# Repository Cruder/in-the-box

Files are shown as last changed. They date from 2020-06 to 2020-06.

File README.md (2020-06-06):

## InTheBox

Connect your mailbox to be notified as soon as you receive mail.
InTheBox is also able to detect and warn you of suspicious behaviors around your mailbox.

demo

### Supplies
#### Circuit
- [Tags 13.56MHz](https://fr.aliexpress.com/item/33026471651.html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,searchweb201602_,searchweb201603_) 
- [RFID module 13.56MHz](https://fr.aliexpress.com/item/32803014822.html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)
- [Arduino Yun](https://store.arduino.cc/arduino-yun)
- [FSR 406](https://fr.aliexpress.com/item/32652992847.html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,searchweb201602_,searchweb201603_)
- [HC-SR04](https://fr.aliexpress.com/item/32973373842.html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,searchweb201602_,searchweb201603_)
- [Buzzer](https://fr.aliexpress.com/item/4000012077642.html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)
- [Pile 6V](https://fr.aliexpress.com/item/32971590400.html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,searchweb201602_,searchweb201603_)
- [RGB LED](https://www.amazon.fr/SODIAL-diode-electroluminescente-tete-ronde/dp/B00F4MGA0I?ref_=fsclp_pl_dp_2)

#### Scale
- 1 board 30 x 41 x 0.5 cm
- [Pressure Sensor Pad GreenS40](https://fr.aliexpress.com/item/4000416208703.html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,searchweb201602_,searchweb201603_)

#### Dummy soil
- 1 board 30 x 41 x 1 cm
- 2 boards 35 x 41 x 1 cm
- 1 board 35 x 28 x 1 cm
- 1 cylinder 35 cm x 1 cm radius
- screws / glue
- Something to cut out of the board 

### Step 1 - Tags initialization
The device uses key badges and an RFID reader to identify the person who opens the mailbox. This allows, among other things, to: 
- Not notify if the mailbox is opened with the badge nearby.
- Notify if mail is added to or removed from the mailbox without a badge nearby.
The drive range is 10 cm.

The first step is to register the badges used using the RFID module.
Copy [the code in the RFID/identify.ino](https://github.com/Cruder/in-the-box/blob/master/RFID/identify.ino) to identify the tags UID, following this fritzing schema:




(Credit code to https://www.electronique-mixte.fr/microcontrolleurs/rfid-controle-dacces-par-badge-avec-arduino/) 

### Step 2 - Assembly of the components
Fritzing schemas:
Fritzing
Fritzing2

### Step 3 - Mailbox measurement
We need to know the dimensions of the mailbox in order to build the layout and configure the distance sensor.
Measures the inner width and depth.

### Step 4 - Web server
#### Requirements
- You must install [Mint Lang](https://www.mint-lang.com).
- If you are using Windows, you will need to install Docker [Docker](https://www.docker.com/get-started).

#### Installation
- Go to the `notifier` folder
- Run `mint install`

#### Run
To start the server, run `mint start`



### Step 5 - Arduino code and component testing
The code is available on this TinkerCAD simulation: https://www.tinkercad.com/things/1rgmoFdLwcb
Copy it to your arduino, then modify this line to indicate the depth of your mailbox in millimetres:
```
#define MAIL_BOX_DEPTH 500
```
Then add the tags UID to the configuration.

Now you'd like to test your component assembly and configuration before moving them into the mailbox.

### Step 6 - Fabrication of dummy soil
The plan has been calculated for a letterbox with the dimensions 30 x 41 x 30 cm (L x W x H).
To readjust the plan to the dimensions of your letterbox, make sure that the false floor board (initially 30 x 41 x 1 cm) passes through the door horizontally before assembling.
supplies
plan cache

If you have a 3D printer, you can find [here](https://github.com/Cruder/in-the-box/tree/master/dummy_soil) a model to print yourself.

Follow these these assembly instructions:
1. Perce a slot in the back centre of the board measuring 30 x 41 x 1 cm, 2 cm wide and 15 cm long. This will allow the FSR sensor wires to disappear under the cover.

Capture d’écran du 2020-06-05 17-51-12

2. Turn the board so that you have the slot in front of you. Attach the 2 boards 35 x 41 x 1 cm on each side vertically to the board. 

Capture d’écran du 2020-06-05 17-54-19

3. On the other side, attach the 35 x 28 x 1 cm board vertically to the main board.

Capture d’écran du 2020-06-05 17-57-36

4. In the centre of the main board, 4 cm from the slot, attach the cylinder. Be careful not to let the screw protrude from the other side of the board, we will install the FSR sensor there.

Capture d’écran du 2020-06-05 17-58-23

### Step 7 - Arrangement of the letter box 
1. Place the arduino and its components at the bottom of the mailbox. The RFID sensor must be placed on the front or rear lock side. Its location will have an impact on the quality of authentication, and you will need to retrieve mail from this side only. 
2. Place the dummy soil in the mailbox, slot towards the back door. Be careful not to crush any components with the support foot of the dummy soil.
3. Fix the FSR sensor in the center of the dummy soil, tab towards the slot so the wires slide beneath. Pass the HC-SR04 sensor through the slot, we will fix it later at the back of the mailbox.
Capture d’écran du 2020-06-05 13-12-44
4. Fix the pressure pad on the FSR sensor.
Capture d’écran du 2020-06-05 13-13-01
5. Place the 30 x 41 x 0.5 cm board on top to make the scale.
Capture d’écran du 2020-06-05 13-26-51
6. Place the HC-SR04 sensor at the back of the mailbox on the side where the lock of the front door is located, and do some tests!
7. Then you can fix the HC-SR04 sensor

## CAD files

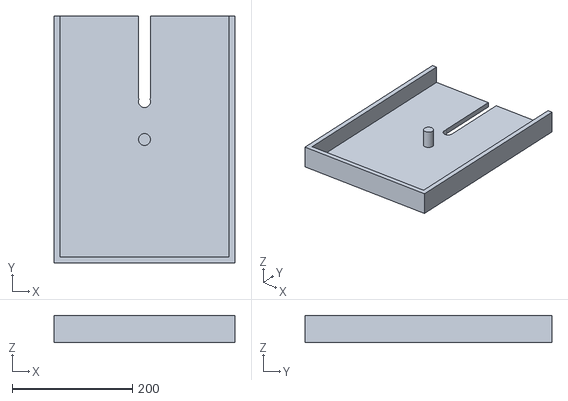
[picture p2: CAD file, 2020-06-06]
dummy_soil/tinker.obj
300.0 x 410.0 x 45.0

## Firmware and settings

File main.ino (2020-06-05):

#include <Keypad.h>

#define PIN_POTEN A0

#define PIN_HC_TRIG 3
#define PIN_HC_ECHO 2

#define RESET_PIN 13

#define PIN_BUZZER 12

// 1 minute, 60 000ms
#define FORCE_TIME_THRESSHOLD 60000UL
// Detect 1% force changes
// this avoid falsey positives
#define FORCE_THRESSHOLD 1

// Echo timeout from the HC module
#define MEASURE_TIMEOUT 25000UL

// Send notif if open 5s
#define DEPTH_MESURE_THRESSHOLD 5000

// Mailbox distance = 500mm
#define MAIL_BOX_DEPTH 500

/* Vitesse du son dans l'air en mm/us */
const float SOUND_SPEED = 340.0 / 1000;

unsigned long previous_force_time;
int previous_force;

// 0 = close
// 1 = openning
// 2 = oppenned
byte door_opening = 0;
unsigned long opening_time;

// Authentication PAD
const byte ROWS = 4;
const byte COLS = 4;
char keys[ROWS][COLS] = {
  {'1','2','3','A'},
  {'4','5','6','B'},
  {'7','8','9','C'},
  {'*','0','#','D'}
};
byte rowPins[ROWS] = {11, 10, 9, 8};
byte colPins[COLS] = {7, 6, 5, 4};

Keypad keypad = Keypad(makeKeymap(keys), rowPins, colPins, ROWS, COLS );

// 0 = not authenticated
// 1 = authenticating (typing password)
// 2 = authenticated
byte authentication = 0;
unsigned long auth_timer;
char password[4];
byte current_pos = 0;

const char secret_password[4] = { '1', '3', '5', '9'};

// 5 minutes
const unsigned long AUTH_DURATION = 60000 * 5;
const unsigned long BUZZER_DURATION = 50;

void resetAll() {
  pinMode(RESET_PIN, OUTPUT);
  digitalWrite(RESET_PIN, LOW);
}

int normalize(
  int value,
  int min_value, int max_value,
  int min_result, int max_result
) {
  int ratio = (max_result - min_result);
  float cursor = (float)(value - min_value) / (float)(max_value - min_value);

  return ratio * cursor + min_result;
}

bool matchPassword() {
  for(int i = 0; i < 4; ++i) {
    if(password[i] != secret_password[i]) { return false; }
  }
  return true;
}

void printPassword() {
  Serial.print("Current size : ");
  Serial.println(current_pos);
  Serial.print("Password : ");

  for(int i = 0; i < current_pos; ++i) {
  	Serial.print(password[i]);
  }

  Serial.println("");
}


int readForce(int pin) {
  int val = analogRead(pin);
  // Normalize to be more resilient when poten
  // will be changed to a FSR (force sensor)
  return normalize(val, 0, 1024, 0, 100);
}

void authenticatedManager() {
  if(millis() - auth_timer > BUZZER_DURATION) {
  	noTone(PIN_BUZZER);
  }

  if(millis() - auth_timer > AUTH_DURATION) {
    authentication = 0;
    Serial.println("Authentication ended");
    resetAll();
  }
}

bool authScenario() {
  char key = keypad.getKey();

  if(key != NO_KEY) {
    if(authentication == 0) {
      auth_timer = millis();
      authentication = 1;

      password[0] = key;
      current_pos = 1;
    } else if(authentication == 1) {
      auth_timer = millis();
      password[current_pos] = key;
      current_pos += 1;

      if(current_pos == 4) {
        current_pos = 0;
        if(matchPassword()) {
          Serial.println("Authenticated");
          authentication = 2;
          tone(PIN_BUZZER, 1000);
        } else {
          Serial.println("Wrong password");
          authentication = 0;
        }
      }
    } else {
      authenticatedManager();
    }

    printPassword();
  } else if(authentication == 2) {
  	authenticatedManager();
  }

  return authentication == 2; // Is Authenticated ?
}

void doorScenario() {
  // clean PIN
  digitalWrite(PIN_HC_TRIG, LOW);
  delayMicroseconds(2);

  // send signal
  digitalWrite(PIN_HC_TRIG, HIGH);
  delayMicroseconds(10);
  digitalWrite(PIN_HC_TRIG, LOW);

  long measure = pulseIn(PIN_HC_ECHO, HIGH, MEASURE_TIMEOUT);
  float distance_mm = measure / 2.0 * SOUND_SPEED;

  if(distance_mm > MAIL_BOX_DEPTH) {
    if(door_opening == 0) {
      door_opening = 1;
      opening_time = millis();
    } else if(door_opening == 1) {
      if(millis() - opening_time > DEPTH_MESURE_THRESSHOLD) {
        door_opening = 2;
        Serial.println("SMS - Door is open");
      }
    } else {
      // The door is open
    }
  } else {
    if(door_opening == 2) {
      Serial.println("SMS - Door is closed");
    }

  	door_opening = 0; // The door is closed
  }
}

void forceScenario() {
  int val = readForce(PIN_POTEN);

  if(millis() - previous_force_time >= FORCE_TIME_THRESSHOLD) {
	previous_force_time = millis();
    if(val - previous_force > FORCE_THRESSHOLD) {
      Serial.println("SMS - Nouveau Courier");
      previous_force = val;
    } else if(val - previous_force < -FORCE_THRESSHOLD) {
      Serial.println("SMS - Courier retirer");
      previous_force = val;
    }
  }
}

void setup() {
  Serial.begin(9600);

  // Buzzer
  pinMode(PIN_BUZZER, OUTPUT);

  // HC PIN
  pinMode(PIN_HC_TRIG, OUTPUT);
  pinMode(PIN_HC_ECHO, INPUT);

  // Initial mesures
  previous_force_time = millis();
  previous_force = readForce(PIN_POTEN);
}

void loop() {
  bool authenticated = authScenario();

  if(!authenticated) {
    doorScenario();
    forceScenario();
  }
  delay(16);
}

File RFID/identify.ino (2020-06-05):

#include <SPI.h> // SPI
#include <MFRC522.h> // RFID

#define SS_PIN 10
#define RST_PIN 9

MFRC522 rfid(SS_PIN, RST_PIN);

byte nuidPICC[4];

void setup()
{
  // Init RS232
  Serial.begin(9600);

  // Init SPI bus
  SPI.begin();

  // Init MFRC522
  rfid.PCD_Init();
}

void loop()
{
  if ( !rfid.PICC_IsNewCardPresent())
    return;

  if ( !rfid.PICC_ReadCardSerial())
    return;

  for (byte i = 0; i < 4; i++)
  {
    nuidPICC[i] = rfid.uid.uidByte[i];
  }

  Serial.println("Tag UID: ");
  for (byte i = 0; i < 4; i++)
  {
    Serial.print(nuidPICC[i], HEX);
    Serial.print(" ");
  }
  Serial.println();

  // Re-Init RFID
  rfid.PICC_HaltA(); // Halt PICC
  rfid.PCD_StopCrypto1(); // Stop encryption on PCD
}

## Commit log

2020-06-05 First version Schema Fritzing
    [inthebox.fzz]
2020-06-05 Fritzing Schema with Yun Arduino (built-in WIFI)
    [inthebox_yun.fzz]
2020-06-05 Fix schema Pressure->FSR
    [inthebox_yun.fzz]
2020-06-05 Change Arduino Uno into an Arduino Yun
2020-06-06 Schema for identifying tag
    [inthebox_identifier.fzz]
2020-06-06 Add dummy soil obj
    [tinker.obj]
